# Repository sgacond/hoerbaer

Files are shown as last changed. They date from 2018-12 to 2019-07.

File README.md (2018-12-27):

# HörBär

## Idea
Build a more advanced, better sounding and better looking big brother of the commercially available [Hörbert](https://www.hoerbert.com/).

## Components
- A wonderful grand-father home made wooden housing. See: [C. Mosberger Restaurierung und Kunsthandwerk](http://www.cmosberger.ch/).
- MCU: ESP32
- PmodI2S DAC
- Adafruit MAX9744 based amplifier board
- Visaton FX 10 5" coaxial speaker

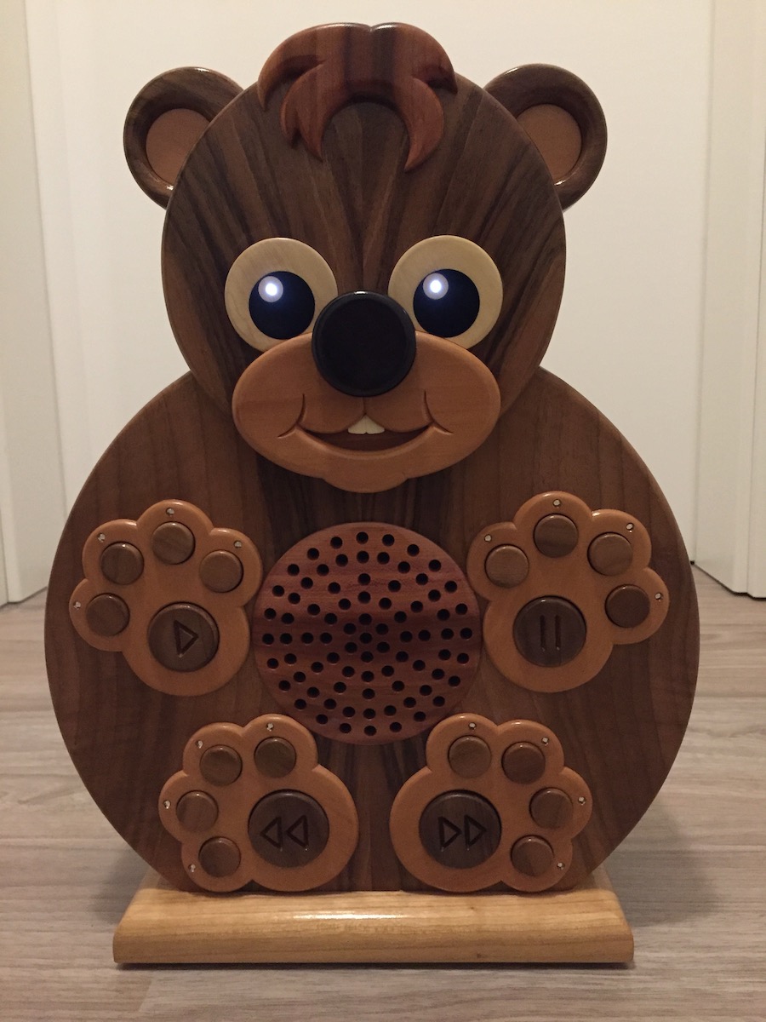
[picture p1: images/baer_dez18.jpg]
Case

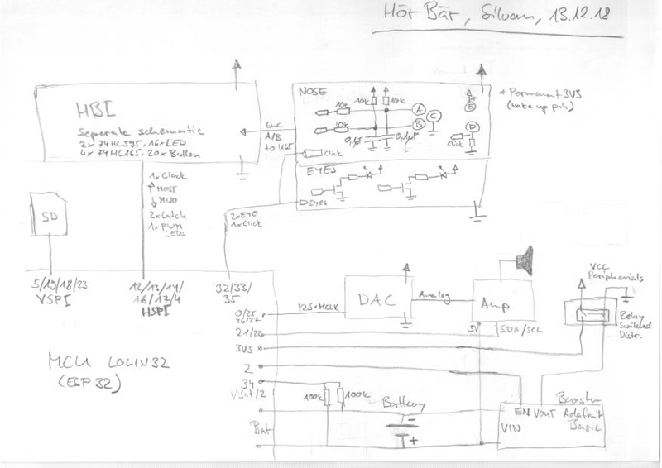
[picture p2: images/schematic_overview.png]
Overview schematic


## Credits
Some of Neil Kolbans [CPP Utils](https://github.com/nkolban/esp32-snippets).  
Ideas and components from [ESP32_MP3_Decoder](https://github.com/MrBuddyCasino/ESP32_MP3_Decoder).  
Thank you!

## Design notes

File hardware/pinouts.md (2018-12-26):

# Hoerbaer Pinout

## LOLIN32
| Pin  | Signal | Peer | Color |
| ---: | ---  | --- | --- |
| IO2  | BOOSTER-EN* | BOOSTER | Brown | 
| IO12 | HBI-MISO | HBI | Blue |
| IO13 | HBI-MOSI | HBI | Violet  |
| IO14 | HBI-CLK | HBI | White |
| IO16 | HBI-LatchIn | HBI | Green |
| IO17 | HBI-LatchOut  | HBI | Gray |
| IO35 | HBI-ENC-CLICK | HBI | Green |
|  IO4 | HBI-PWMLED | HBI | Yellow  |
| IO32 | HBI-EYE0 | HBI | White |
| IO33 | HBI-EYE1 | HBI | Gray |
|  IO0 | DAC-MCK | DAC | Blue |
| IO25 | DAC-LRCK | DAC | Green |
| IO26 | DAC-SCK | DAC | Yellow  |
| IO27 | DAC-SDIN | DAC | Orange  |
| IO21 | AMP-SDA | AMP | Yellow  |
| IO22 | AMP-SCK | AMP | Orange  |
| IO15 | AMP-MUTE | AMP | Orange  |
| IO34 | VBAT/2 | BAT | Yellow  |
| IO19 | D0 / MISO | SD | Brown |
|  IO5 | D3 / CS | SD | Green |
| IO18 | CLK | SD | Orange  |
| IO23 | CMD / MOSI | SD | Yellow  |  

(* all other peripherials switched with this line)

## NOSE / EYE PCB
| Signal | Color |
| --- | --- |
| GND | Black |
| LED EYE | White |
| LED EYE | Gray |
| ENC A | Violet  |
| ENC B | Blue |
| ENC Click | Green |
| VCC 3V3 | Yellow  |

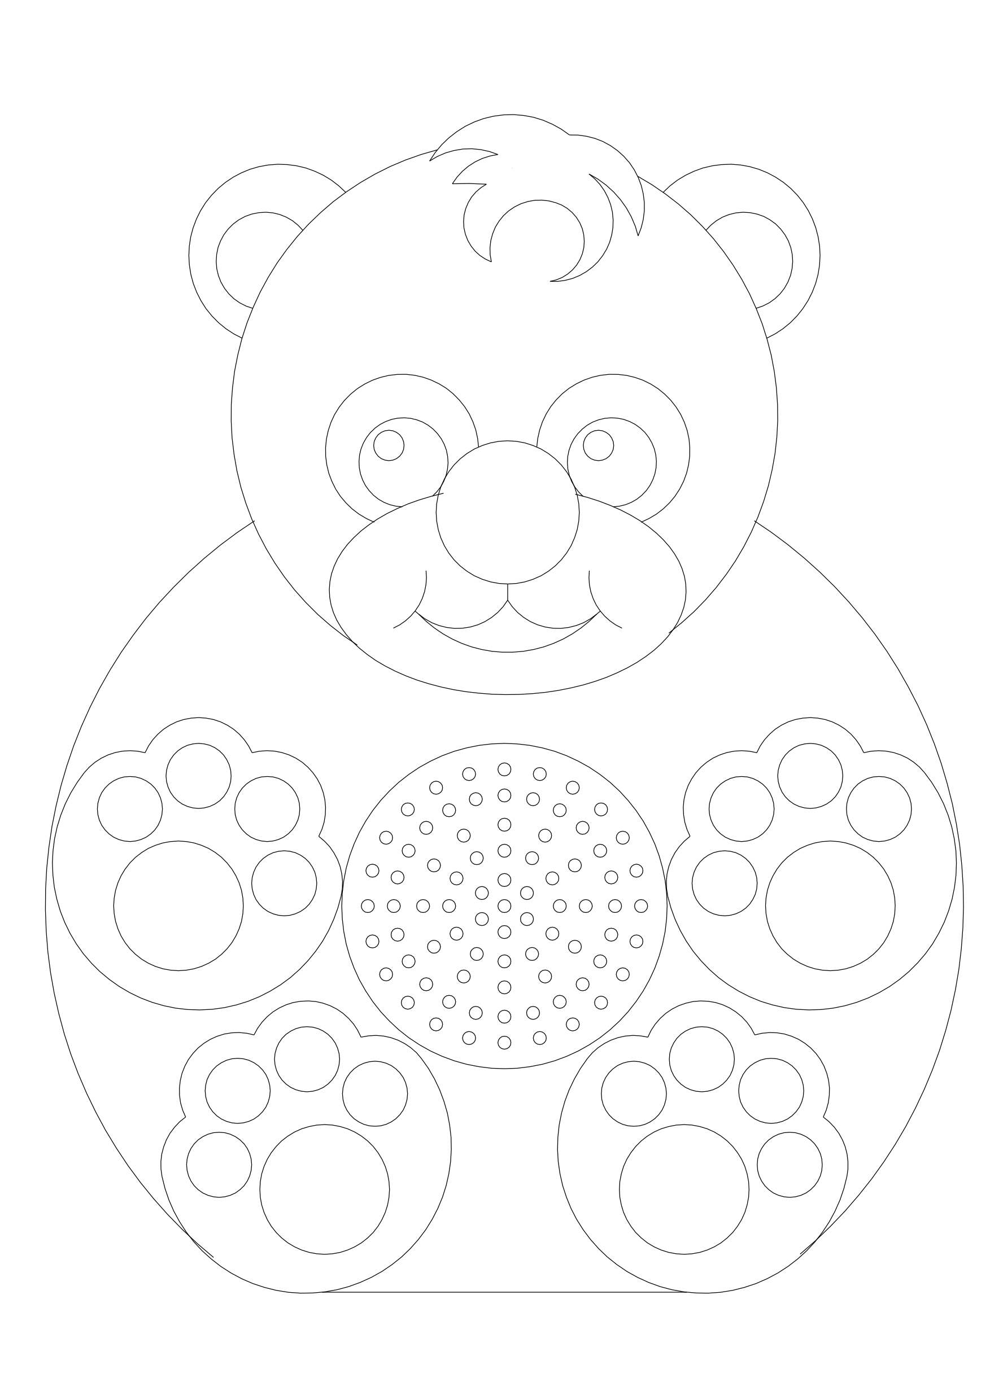
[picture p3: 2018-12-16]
hardware/HBI_addresses.png

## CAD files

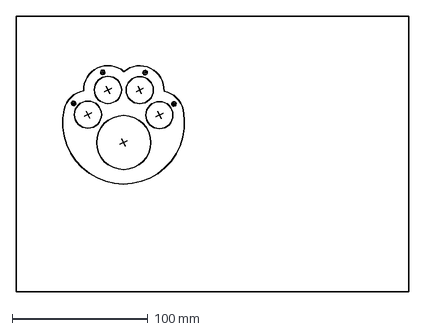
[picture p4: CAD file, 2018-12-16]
hardware/HoerbaerTatze/Pfote.dxf
289.0 x 203.0 mm

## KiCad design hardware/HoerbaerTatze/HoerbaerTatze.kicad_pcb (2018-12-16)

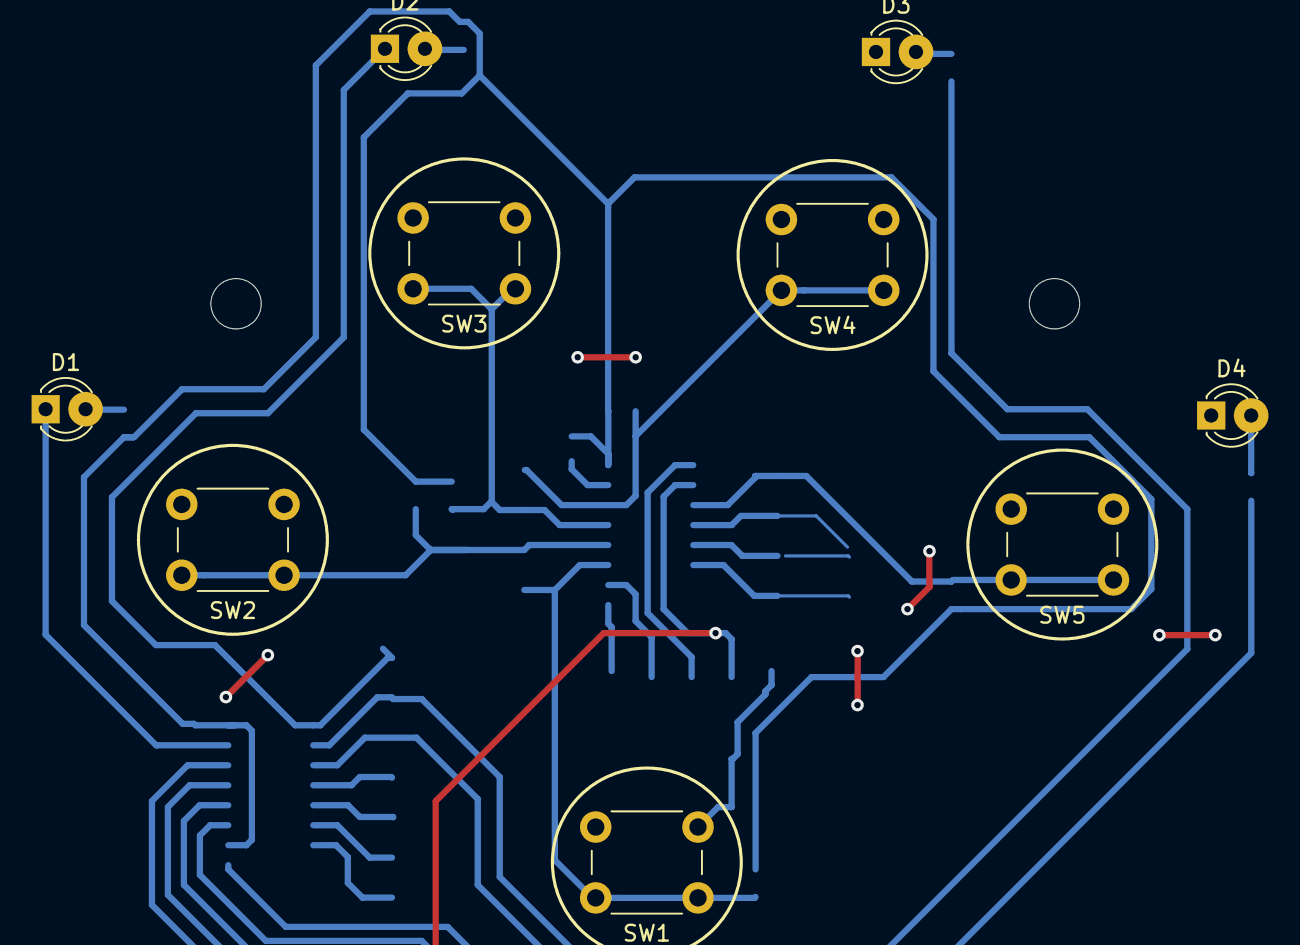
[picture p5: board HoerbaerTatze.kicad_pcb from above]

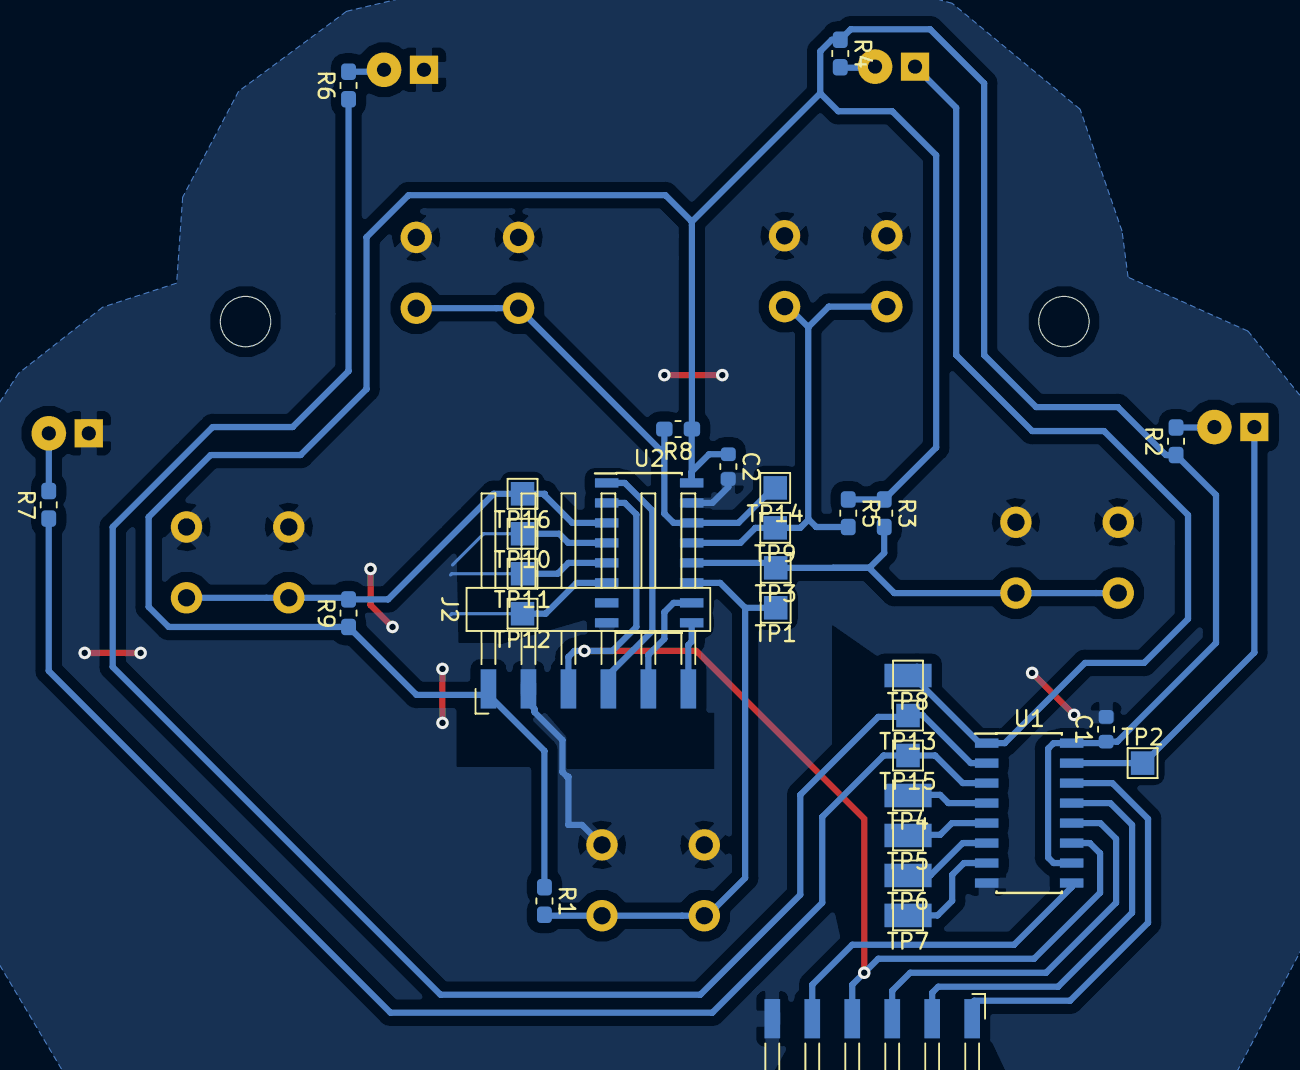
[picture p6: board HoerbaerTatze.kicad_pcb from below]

Board: 2 copper layers, 43 parts (31 on the bottom side), 27 nets.

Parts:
C1, C2: C; C_0603_1608Metric
D1, D2, D3, D4: LED; LED_D3.0mm
J1, J2: SWITCH; Harwin_M20-89006xx_1x06_P2.54mm_Horizontal
MH1, MH3, MH4: MountingHole; MountingHole_3.2mm_M3
R1, R3, R5, R8, R9: 10k; R_0603_1608Metric_Pad1.05x0.95mm_HandSolder
R2, R4, R6, R7: R; R_0603_1608Metric_Pad1.05x0.95mm_HandSolder
SW1, SW2, SW3, SW4, SW5: SW_Push; SW_PUSH_6mm
TP1, TP2, TP3, TP4, TP5, TP6, TP7, TP8, TP9, TP10, TP11, TP12, TP13, TP14, TP15, TP16: TestPoint; TestPoint_Pad_1.5x1.5mm
U1: 74HC595; SOIC-16_3.9x9.9mm_P1.27mm
U2: 74HC165; SOIC-16_3.9x9.9mm_P1.27mm

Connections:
CHAIN_SERIAL_IN: J2.5, U2.10
CHAIN_SERIAL_OUT: J1.5, U1.9
CLK: J1.4, J2.3, U1.11, U2.2
GND: C1.2, C2.2, D3.1, D4.1, J1.6, J2.2, SW1.1, SW2.1, SW3.1, SW4.1, SW5.1, TP10.1, TP11.1, TP12.1, U1.8, U2.4, U2.5, U2.6, U2.8, U2.15
IN_LATCH: J2.4, U2.1
LED1_LOW: D1.1, TP2.1, U1.15
LED2_LOW: D2.1, TP8.1, U1.1
LED3_HIGH: R6.1, TP13.1, U1.2
LED4_HIGH: R7.1, TP15.1, U1.3
LED_DIM_PWM: J1.2, U1.13
MISO: J2.6, U2.9
MOSI: J1.1, U1.14
unnamed: D1.2, R2.2
unnamed: D2.2, R4.2
unnamed: D3.2, R6.2
unnamed: D4.2, R7.2
unnamed: TP4.1, U1.4
unnamed: TP5.1, U1.5
unnamed: TP6.1, U1.6
unnamed: TP7.1, U1.7
OUT_LATCH: J1.3, U1.12
SW1: R1.2, SW1.2, TP1.1, U2.11
SW2: R3.2, SW2.2, TP3.1, U2.12
SW3: R5.2, SW3.2, TP9.1, U2.13
SW4: R8.2, SW4.2, TP14.1, U2.14
SW5: R9.2, SW5.2, TP16.1, U2.3
VCC: C1.1, C2.1, J2.1, R1.1, R2.1, R3.1, R4.1, R5.1, R8.1, R9.1, U1.10, U1.16, U2.16

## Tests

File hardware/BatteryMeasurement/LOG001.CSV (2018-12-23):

PCB: 008
ASM: 000
LOT: 00000
FW:  1477971088
CH1:  AMPS   10A
CH2:  VOLT   60V
SMPL: 0032 0125Hz
UTC TIME SEC  ,CH1 AMPS DC  ,CH2 VOLT DC

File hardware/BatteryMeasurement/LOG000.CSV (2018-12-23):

PCB: 008
ASM: 000
LOT: 00000
FW: 1477971088
CH1: AMPS 10A
CH2: VOLT 60V
SMPL: 0032 0125Hz
UTC TIME SEC | CH1 AMPS DC | CH2 VOLT DC
1545556289.166 | -2.827167E-03 | 4.144850E000
1545556289.873 | -2.798318E-03 | 4.144777E000
1545556300.215 | -2.788702E-03 | 4.144814E000
1545556310.490 | -2.836783E-03 | 4.144868E000
1545556320.761 | -2.807934E-03 | 4.144924E000
1545556332.760 | -2.827167E-03 | 4.145327E000
1545556342.760 | -2.812743E-03 | 4.145418E000
1545556352.760 | -2.817551E-03 | 4.145436E000
1545556362.761 | -2.827167E-03 | 4.145528E000
1545556372.761 | -2.817551E-03 | 4.145455E000
1545556382.760 | -2.831975E-03 | 4.145473E000
1545556392.761 | -2.807934E-03 | 4.145510E000
1545556402.761 | -2.836783E-03 | 4.145491E000
1545556412.756 | -2.798318E-03 | 4.145491E000
1545556422.761 | -2.822359E-03 | 4.145510E000
1545556432.761 | -2.831975E-03 | 4.145473E000
1545556442.761 | -2.822359E-03 | 4.145473E000
1545556452.761 | -2.831975E-03 | 4.145510E000
1545556462.761 | -2.822359E-03 | 4.145473E000
1545556472.761 | -2.822359E-03 | 4.145491E000
1545556482.761 | -2.817551E-03 | 4.145491E000
1545556492.761 | -2.812743E-03 | 4.145491E000
1545556502.761 | -2.827167E-03 | 4.145436E000
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

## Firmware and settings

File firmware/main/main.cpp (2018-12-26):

#include "HoerBaer.h"
#include "../Configuration.h"
#include "esp_sleep.h"

extern "C" {
    void app_main();
}

void app_main() {
    auto baer = new HoerBaer();
    baer->run();
    delete baer;
    
    printf("Enabling EXT1 wakeup on pin GPIO%d\n", PIN_HBI_NOSE_CLK);
    esp_sleep_enable_ext1_wakeup(1ULL << PIN_HBI_NOSE_CLK, ESP_EXT1_WAKEUP_ANY_HIGH);

    printf("Good night...\n");
    esp_deep_sleep_start();
}

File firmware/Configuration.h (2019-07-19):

#ifndef CONFIGURATION_H_
#define CONFIGURATION_H_

#include <freertos/FreeRTOS.h>
#include <freertos/task.h>

#include "driver/gpio.h"
#include "driver/i2s.h"
#include "driver/spi_master.h"

#define MAIN_NTHLOOP_BATCHK 25 //256 // every nth loop - battery check

#define PIN_PERIPH_MAIN     GPIO_NUM_2

#define ADC_VBAT            ADC1_CHANNEL_6 // PIN 34
#define ADC_VBAT_UNIT       ADC_UNIT_1
#define ADC_VBAT_ATTEN      ADC_ATTEN_DB_11
#define ADC_VBAT_WIDTH      ADC_WIDTH_BIT_12
#define ADC_VBAT_MULTISMPL  64
#define ADC_VBAT_VDIV       2 // applied volatage divider

#define SPI_HOST_SDCARD     VSPI_HOST
#define PIN_SDCARD_MISO     GPIO_NUM_19
#define PIN_SDCARD_MOSI     GPIO_NUM_23
#define PIN_SDCARD_CLK      GPIO_NUM_18
#define PIN_SDCARD_CS       GPIO_NUM_5

#define TSK_PRIO_WAVPLAY    configMAX_PRIORITIES - 2
#define I2S_NUM             I2S_NUM_0
#define PIN_I2S_BCK         GPIO_NUM_26
#define PIN_I2S_LRCK        GPIO_NUM_25
#define PIN_I2S_OUT         GPIO_NUM_27

#define PIN_I2C_SDA         GPIO_NUM_21
#define PIN_I2C_SCL         GPIO_NUM_22
#define AMP_I2C_ADDR        0x4B
#define AMP_I2C_RETRIES     5
#define AMP_I2C_CLOCK       10000 // was 100kHz - but with long wires and this payload 10k is enough. Signal looks way better on the scope.
#define AMP_MAX_VOL         26 // 63 is technically max - but not funny with little dj-leya sometimes ;)
#define AMP_INIT_VOL        18
#define PIN_AMP_MUTE        GPIO_NUM_15

#define TSK_PRIO_HBI        configMAX_PRIORITIES - 4
#define TSK_PRIO_HBISHIFT   configMAX_PRIORITIES - 1
#define TIME_HBISHIFT_OP_MS 20
#define QUEUE_LEN_HBISHIFT  10
#define QUEUE_LEN_HBICMD    10
#define CMD_QUEUE_BLOCK_MS  200
#define HBI_NOSE_SHUT_TICKS 120
#define SPI_HOST_HBI        HSPI_HOST
#define PIN_HBI_MISO        GPIO_NUM_12
#define PIN_HBI_MOSI        GPIO_NUM_13
#define PIN_HBI_CLK         GPIO_NUM_14
#define PIN_HBI_LIN         GPIO_NUM_16
#define PIN_HBI_LOUT        GPIO_NUM_17
#define PIN_HBI_PWM         GPIO_NUM_4
#define PIN_HBI_EYEL        GPIO_NUM_32
#define PIN_HBI_EYER        GPIO_NUM_33
#define PIN_HBI_NOSE_CLK    GPIO_NUM_35

#endif

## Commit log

2018-10-22 Added better dynamic wave header parsing.
    [Configuration.h]
2018-10-22 Wip: audio, ...
    [Configuration.h]
2018-12-16 wip: firmware, ui prototype and boilerplate
    [Configuration.h, HoerbaerTatze.kicad_pcb, HoerbaerTatze.sch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]
2018-12-18 Bear is talking - nose can adjust volume... Much to do!
    [Configuration.h]
2018-12-21 WIP: audio playing.
    [Configuration.h]
2018-12-23 WIP: playing, sleeping, pause, resume, ...
    [Configuration.h, LOG000.CSV, LOG001.CSV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]
2018-12-26 Some fixes after successful christmas presentation to the client ;).
    [Configuration.h]
2018-12-26 GPIO15 amp fix, SPI CS was selected.
    [HBI.cpp, HBIShift.cpp, HoerBaer.cpp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]
2019-07-19 Changed max volume (no technical reason ;))
    [Configuration.h]
